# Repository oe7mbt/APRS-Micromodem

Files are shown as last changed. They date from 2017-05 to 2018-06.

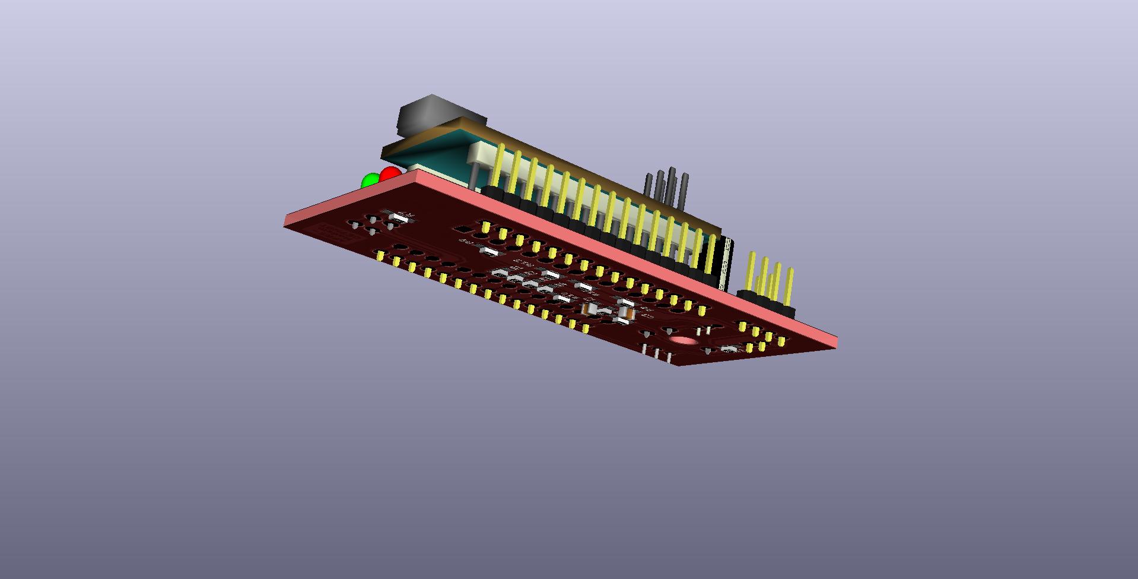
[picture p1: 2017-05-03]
Pictures/APRS_Micromodem_OE7MBT.jpg

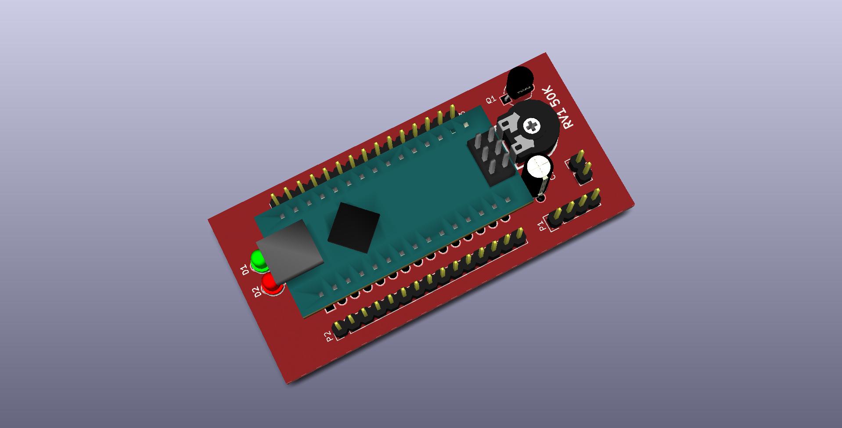
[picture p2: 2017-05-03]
Pictures/APRS_Micromodem_OE7MBT1.jpg

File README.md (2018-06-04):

# APRS-Micromodem

Die Schaltung basiert auf der Entwicklung von Mark Qvist aus Dänemark (http://unsigned.io/projects/microaprs/), der auch die Firmware als Open-Source bereitstellt. Ebenso gibt es eine Libary für eigene Entwicklungen in der Arduino-Entwicklungsumgebung.

Ich habe diese Schaltung für meine Zwecke angepasst und dafür eine Platine erstellt, die einerseits auf einem kostengünstigen Arduino Nano basiert und andererseits für Experimente leicht erweiterbar ist.

Die Pins des Arduino sind (z.B für den Anschluß eines GPS-Modules oder eines Displays) auf einer Pinleiste direkt abgrefbar. Weiters gibt es auch eine I2C-Schnittstelle für die Kommunikation mit weiterer Hardware.

73 de Marco, OE7MBT

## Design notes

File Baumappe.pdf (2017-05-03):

# Baumappe APRS-Modem

## Marco, OE7MBT

## Schaltplan

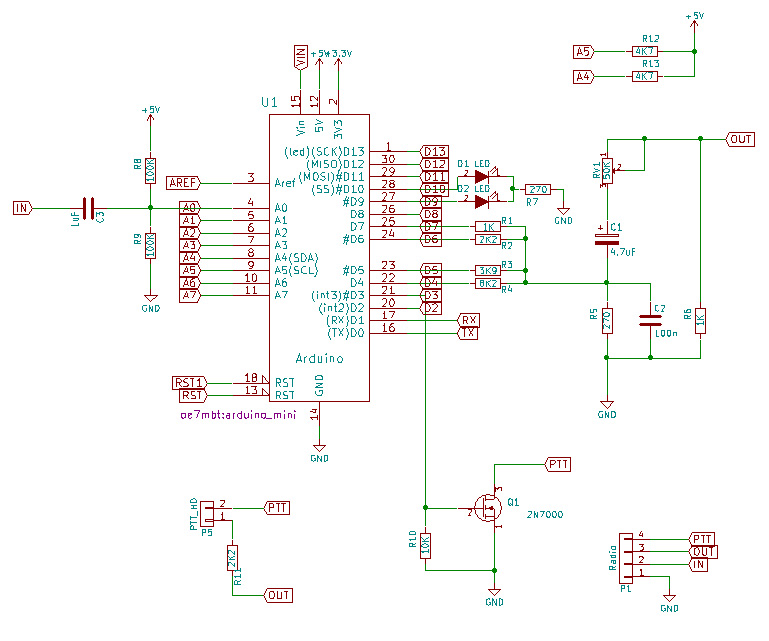
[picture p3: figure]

## Stückliste

Anzahl | Bezeichner | Wert | Bauteil | Anmerkung
2 | R1,R6 | 1K | SMD 0805
2 | R2,R11 | 2K2 | SMD 0805
1 | R3 | 3K9 | SMD 0805
1 | R4 | 8K2 | SMD 0805
2 | R5,R7 | 270 | SMD 0805
2 | R8,R9 | 100K | SMD 0805
1 | R10 | 10K | SMD 0805
2 | R12,R13 | 4K7 | SMD 0805 | Optional für I2C
1 | C1 | 4.7uF | Elko | Rastermaß 2 oder 5mm
1 | C2 | 100nF | SMD 0805
1 | C3 | 1uF | SMD 0805
1 | Q1 | 2N7000 | TO-92
1 | D1 | LED | LED 3mm Grün
1 | D2 | LED | LED 3mm Rot
1 | RV1 | 50K | Trimmer Piher PT10
1 | P1 | Radio | Pinleiste 1x4
1 | P2 | Arduino 1-15 | Pinleiste 1x15
1 | P3 | Arduino 16-30 | Pinleiste 1x15
1 | P5 | PTT_HD | Pinleiste 1x2
1 | U1 | Arduino | Arduino Nano

## Bestückung SMD-Bauteile

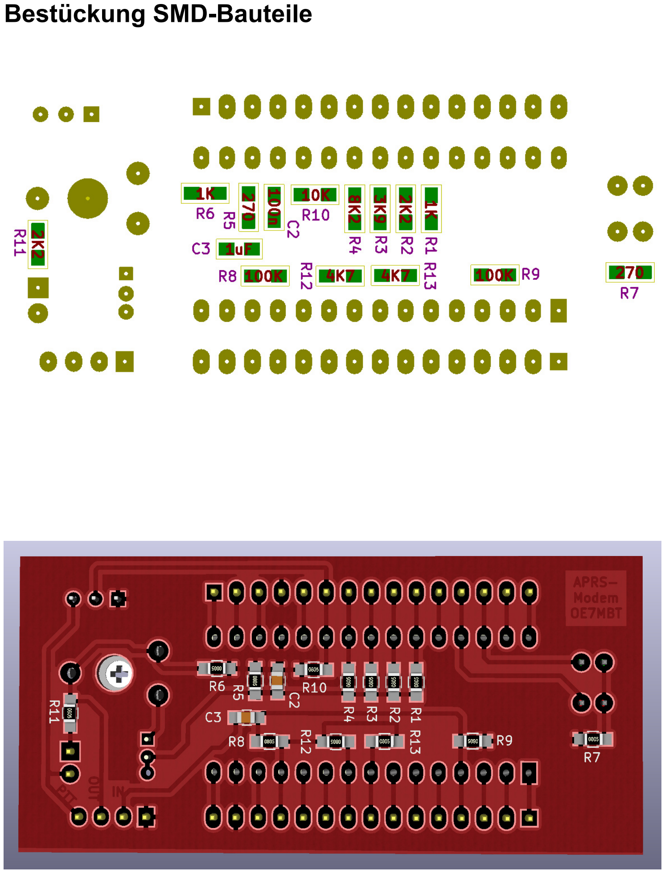
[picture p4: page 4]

## Bestückung bedrahtete Bauteile

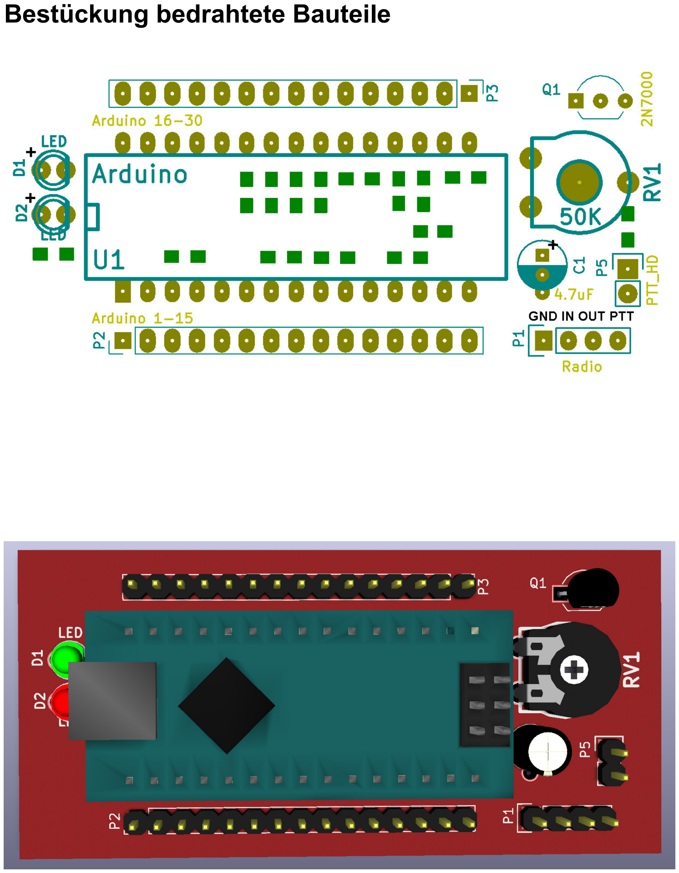
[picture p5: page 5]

## Software

### http://unsigned.io/projects/microaprs/

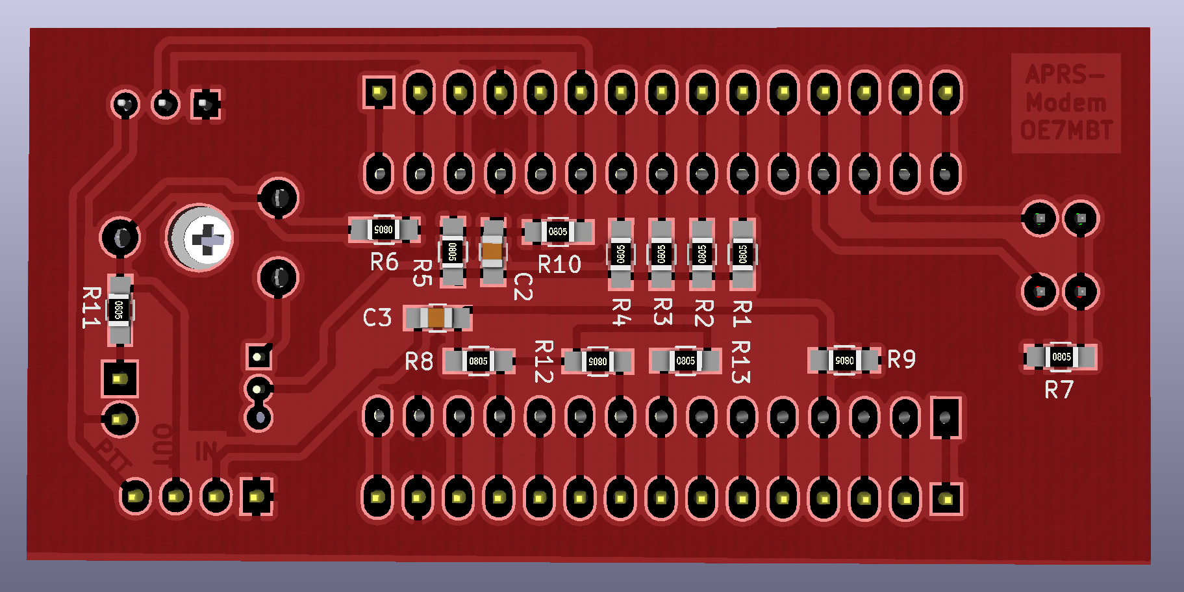
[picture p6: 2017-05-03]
Pictures/3D_SMD.jpg

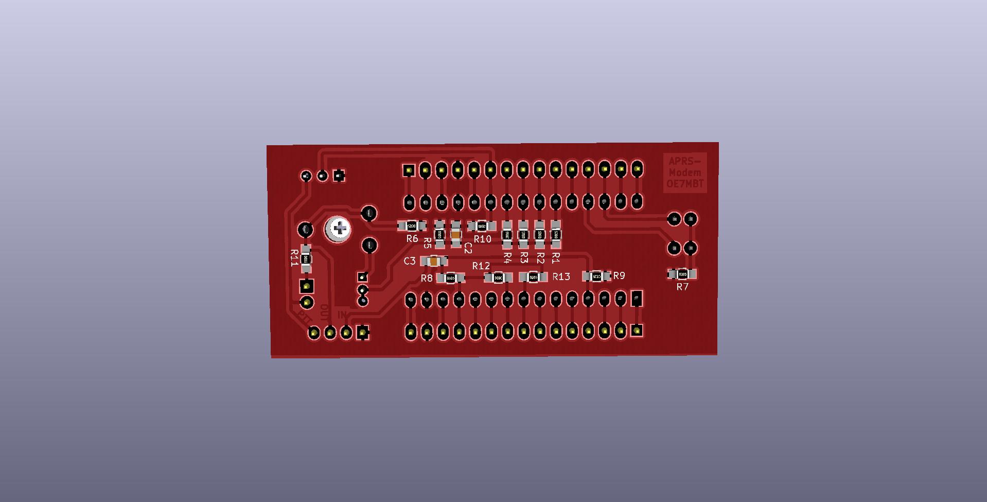
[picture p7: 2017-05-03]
Pictures/APRS_Micromodem_OE7MBT2.jpg

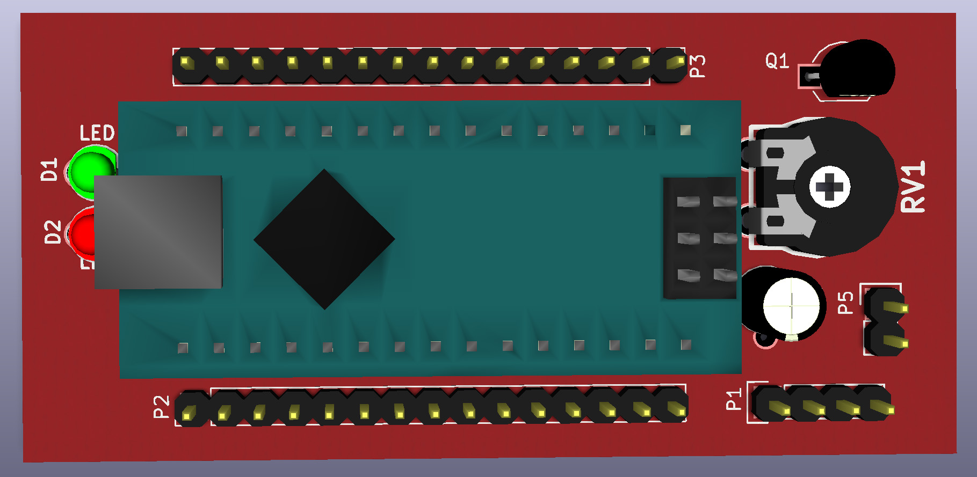
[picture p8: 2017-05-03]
Pictures/3D_THT.jpg

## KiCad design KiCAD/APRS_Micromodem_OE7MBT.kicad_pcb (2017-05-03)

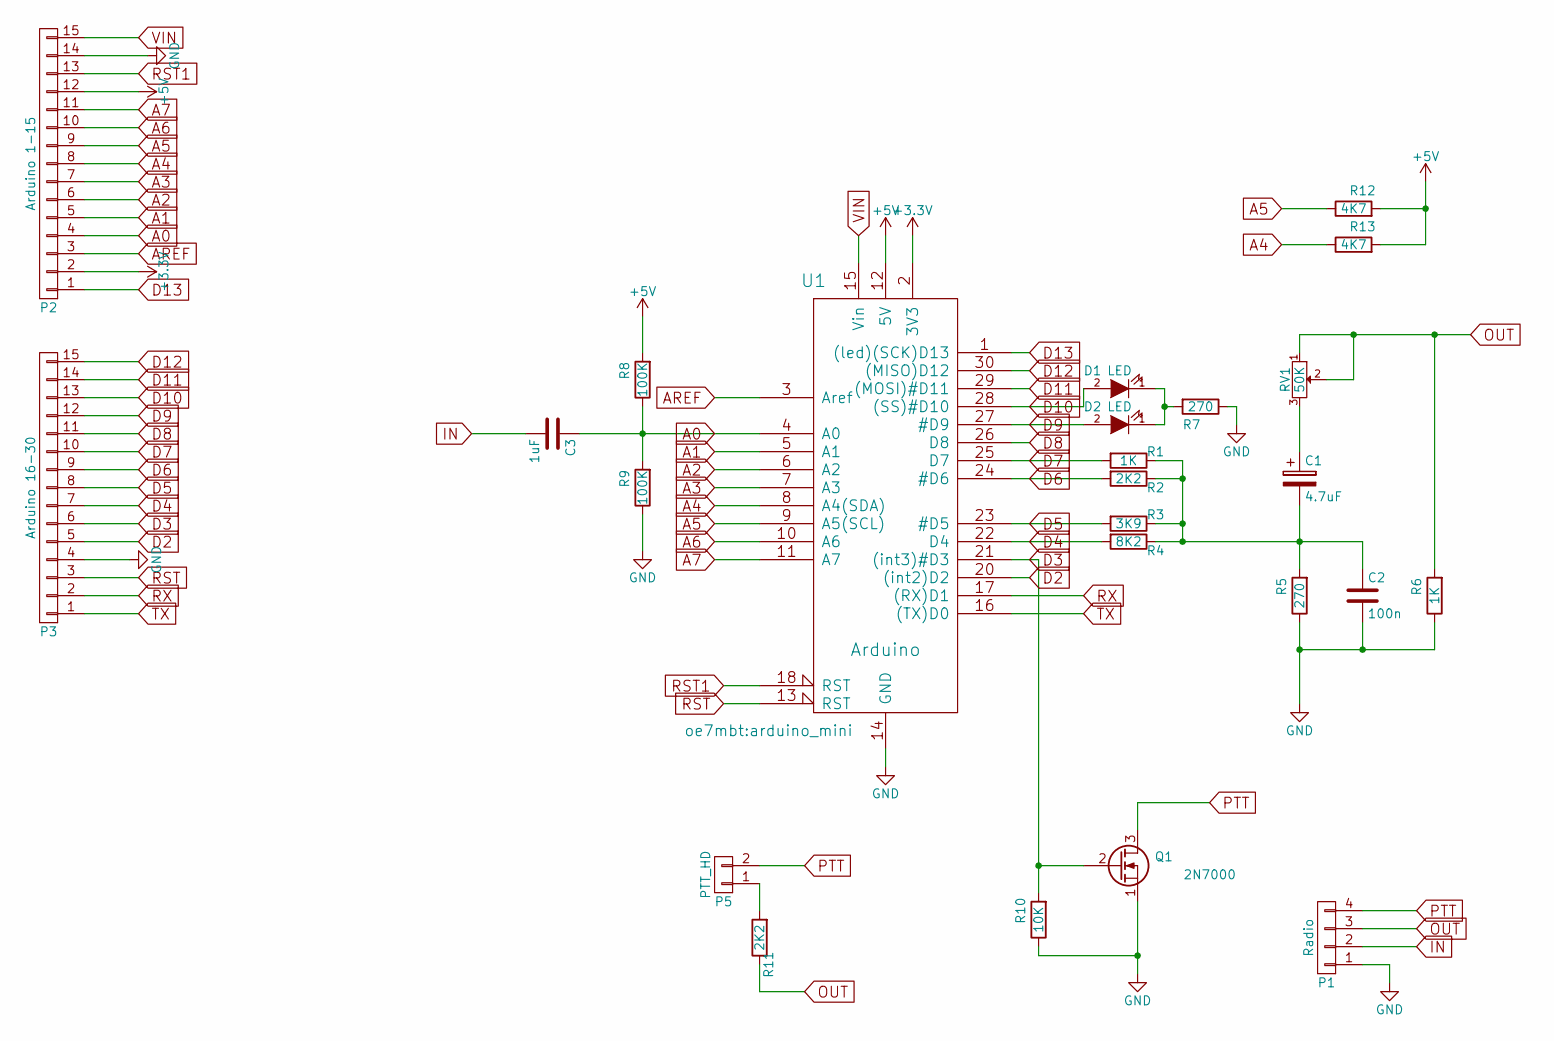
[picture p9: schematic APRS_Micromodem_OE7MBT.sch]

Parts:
C1: 4.7uF; C_Radial_D5_L11_P2
C2: 100n; C_0805_HandSoldering
C3: 1uF; C_0805_HandSoldering
D1: LED; led_3mm_green
D2: LED; led_3mm_red
P1: Radio; Pin_Header_Straight_1x04
P2: Arduino 1-15; Pin_Header_Straight_1x15_Pitch2.54mm
P3: Arduino 16-30; Pin_Header_Straight_1x15_Pitch2.54mm
P5: PTT_HD; Pin_Header_Straight_1x02
Q1: 2N7000; TO-92_Inline_Wide
R1, R6: 1K; R_0805_HandSoldering
R2, R11: 2K2; R_0805_HandSoldering
R3: 3K9; R_0805_HandSoldering
R4: 8K2; R_0805_HandSoldering
R5, R7: 270; R_0805_HandSoldering
R8, R9: 100K; R_0805_HandSoldering
R10: 10K; R_0805_HandSoldering
R12, R13: 4K7; R_0805_HandSoldering
RV1: 50K; trimmer_piher_pt10xv10
U1: Arduino; arduino_mini

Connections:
+3V3: P2.2, U1.2 (3V3)
+5V: P2.12, R8.2, R12.2, R13.2, U1.12 (5V)
A0: C3.1, P2.4, R8.1, R9.2, U1.4 (A0)
A1: P2.5, U1.5 (A1)
A2: P2.6, U1.6 (A2)
A3: P2.7, U1.7 (A3)
A4: P2.8, R13.1, U1.8 (A4(SDA))
A5: P2.9, R12.1, U1.9 (A5(SCL))
A6: P2.10, U1.10 (A6)
A7: P2.11, U1.11 (A7)
AREF: P2.3, U1.3 (Aref)
D2: P3.5, U1.20 ((int2)D2)
D3: P3.6, Q1.2 (G), R10.2, U1.21 ((int3)#D3)
D4: P3.7, R4.2, U1.22 (D4)
D5: P3.8, R3.2, U1.23 (#D5)
D6: P3.9, R2.2, U1.24 (#D6)
D7: P3.10, R1.2, U1.25 (D7)
D8: P3.11, U1.26 (D8)
D9: D2.2 (A), P3.12, U1.27 (#D9)
D10: D1.2 (A), P3.13, U1.28 ((SS)#D10)
D11: P3.14, U1.29 ((MOSI)#D11)
D12: P3.15, U1.30 ((MISO)D12)
D13: P2.1, U1.1 ((led)(SCK)D13)
GND: C2.2, P1.1, P2.14, P3.4, Q1.1 (S), R5.1, R6.1, R7.1, R9.1, R10.1, U1.14 (GND), U1.19 (GND)
IN: C3.2, P1.2
unnamed: C1.1, RV1.3
unnamed: C1.2, C2.1, R1.1, R2.1, R3.1, R4.1, R5.2
unnamed: D1.1 (K), D2.1 (K), R7.2
unnamed: P5.1, R11.2
OUT: P1.3, R6.2, R11.1, RV1.1, RV1.2
PTT: P1.4, P5.2, Q1.3 (D)
RST: P3.3, U1.13 (RST)
RST1: P2.13, U1.18 (RST)
RX: P3.2, U1.17 ((RX)D1)
TX: P3.1, U1.16 ((TX)D0)
VIN: P2.15, U1.15 (Vin)

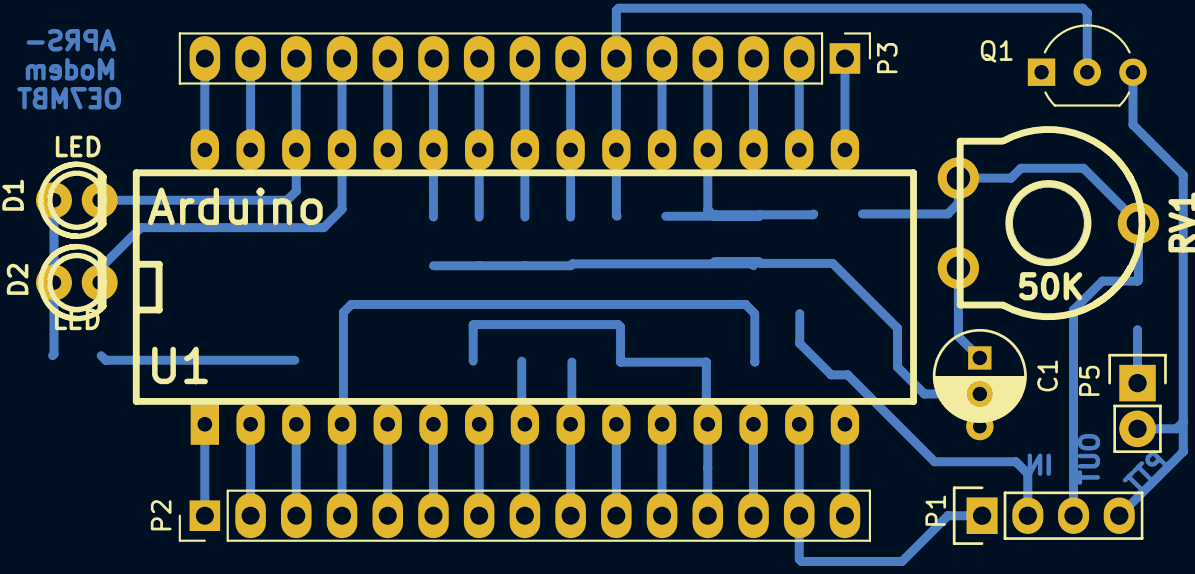
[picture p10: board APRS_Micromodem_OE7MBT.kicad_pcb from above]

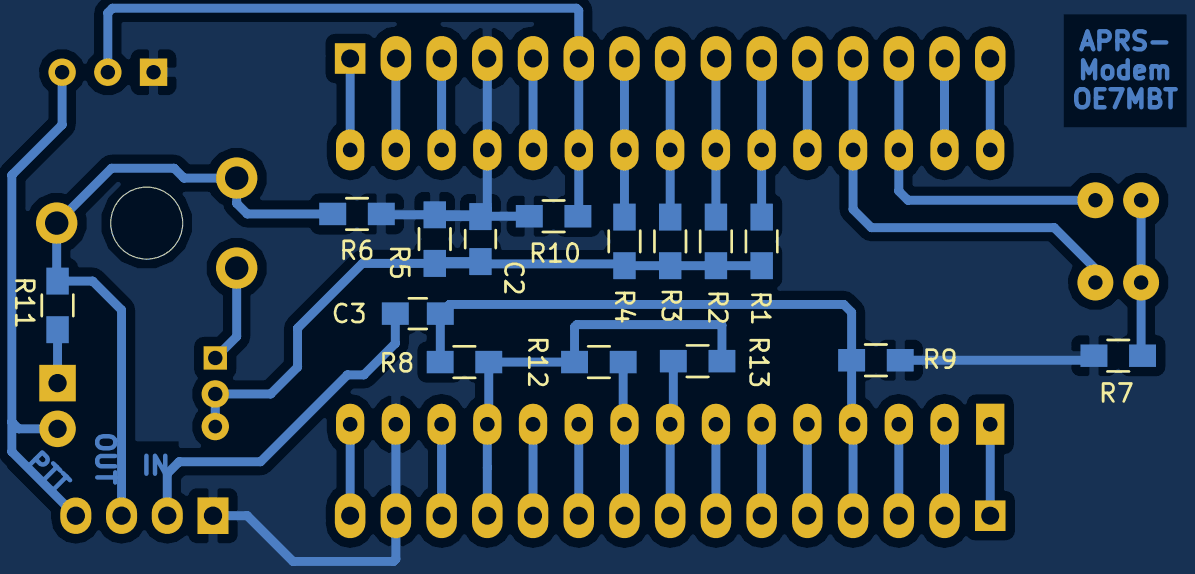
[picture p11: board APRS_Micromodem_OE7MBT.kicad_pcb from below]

Board: 2 copper layers, 25 parts (15 on the bottom side), 36 nets.
